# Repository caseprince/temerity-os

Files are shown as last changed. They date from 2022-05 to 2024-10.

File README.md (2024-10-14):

# temerity-os

Arduino code &amp; docs for bike-mounted rainbow LEDs

Bicycle with Rainbow LEDs

## CAD Models for 3D Printing Designed in OnShape

- [Control Unit Enclosure & Brackets](https://cad.onshape.com/documents/c0d84c6ffa9bdc5b4e96d84a/w/ab7fa442840c19dcdb86b606/e/6a70e81d8de3d289a5feaf4a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)
- [LED brackets](https://cad.onshape.com/documents/a2c029861f4f6949a2b490da/w/bb1c7454e5ed916324910a7b/e/fb98fe964bbb7c3be6a0288d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) for [silicone diffused NeoPixel strips](https://www.adafruit.com/product/3869)

## Toolpaths for laser-cut acrylic back & face plates

- https://github.com/caseprince/temerity-os/tree/main/lazer-toolpaths
- https://www.ponoko.com/ is a great option

## Full Hardware List & Notes

1. 12v Battery. [This one from TalentCell](https://talentcell.com/lithium-ion-battery/12v/pb120b1.html) works well and lasts all night. A LiFePO4 like [this one from Bioenno](https://powerwerx.com/bioenno-blf-1212a-12v-12ah-lithium-iron-pvc) might also be a sweet spot (needs testing.)
2. [Female 12v DC Power Jack Connector](https://www.amazon.com/Ksmile%C2%AE-Female-2-1x5-5mm-Adapter-Connector/dp/B015OCV5Y8/) & cable.
3. Main board is a [Feather](https://learn.adafruit.com/adafruit-feather/overview) from Adafruit: [HalloWing M4](https://www.adafruit.com/product/4300) ([DigiKey links](https://www.digikey.com/en/products/category/evaluation-boards/2041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) may be available for stuff that's out of stock on adafruit.com. There are many [Feathers](https://learn.adafruit.com/adafruit-feather/overview) to choose from, but the HalloWing is shaped like a 💀!)
4. 3.3V Converter for powering Feather: [MPM3610 3.3V Buck Converter Breakout - 21V In 3.3V Out at 1.2A](https://www.adafruit.com/product/4683)
5. [NEOPXL8 FeatherWing](https://www.adafruit.com/product/3249) - This allows for 7-8 NeoPixel channels ([8 if I could figure out compatible pin assignment?](https://forums.adafruit.com/viewtopic.php?p=964067#p964067)), and the screw-down-connection headers allow for easy wiring directly to JST connectors (below).
6. [NeoPixel RGB Neon-like LED Flex Strip with Silicone Tube - 1 meter](https://www.adafruit.com/product/3869) - These are powered directly from the 12V battery.
7. [NeoTrellis](https://learn.adafruit.com/adafruit-neotrellis) with [Silicone Elastomer 4x4 Button Keypad](https://www.adafruit.com/product/1611)- I2C neopixel buttons!
8. Bits and Bobs: [JST Connectors x10](https://www.adafruit.com/product/1663), [White Nylon Machine Screw and Stand-off Set – M2.5 Thread](https://www.adafruit.com/product/3658), [Heat Shrink Pack](https://www.adafruit.com/product/344), 500–1000+ µF Capacitor as per [Adafruit NeoPixel Überguide](https://learn.adafruit.com/adafruit-neopixel-uberguide/best-practices)
9. USB routing for external programming port: [Micro USB elbow thing](https://www.aliexpress.us/item/3256803950842339.html), [Panel Mount Extension](https://www.adafruit.com/product/3258)

### Optional Upgrade

1. [DotStar Digital LED Strips](https://www.adafruit.com/product/2328) - These require beefy 5v converters, eg: [UBEC DC/DC Step-Down (Buck) Converter - 5V @ 3A output](https://www.adafruit.com/product/1385)

### Future Features

- There are 2 holes in the enclosure sized for [Panel Mount 1/8" / 3.5mm TRS Audio Jack Connectors](https://www.adafruit.com/product/3692). These could be for external GPIO, audio in and/or out for sound reactivity, BPM detection, or bicycle bell sound-effects?

### Some Modes:

## Spinning Beachball of Death

Bicycle with Animated Rainbow LEDs

*All the pixels know where they are relative to each other in 3D space with XYZ coords, which makes it a joy to program spatial animations like this rotating rainbow.*

## Green Bounce
Bicycle with Animated Bouncing LEDs

## Purple Sine
Bicycle with Animated Purple LEDs

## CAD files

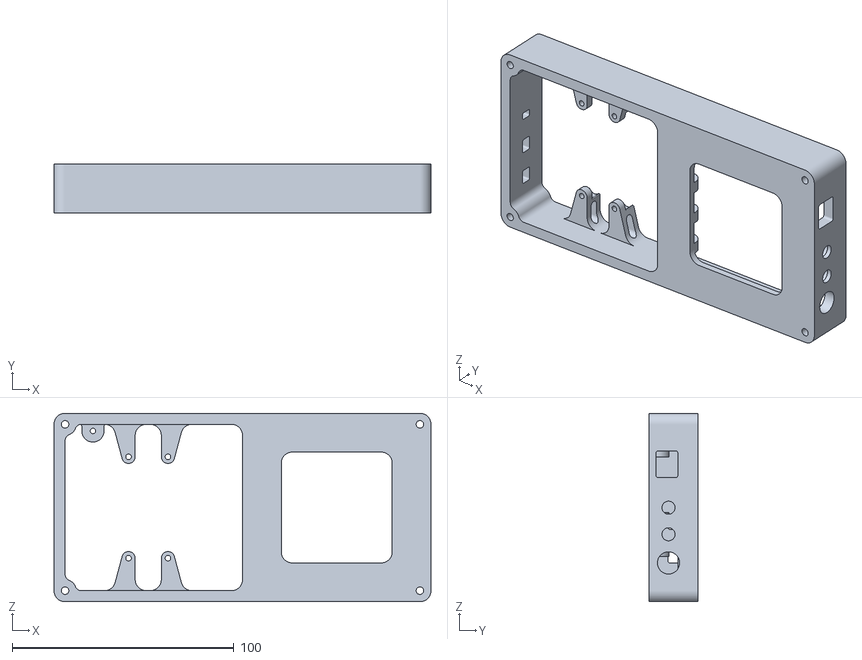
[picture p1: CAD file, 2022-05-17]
yemerityHelm_primaryModuleBody.stl
170.0 x 22.0 x 85.0

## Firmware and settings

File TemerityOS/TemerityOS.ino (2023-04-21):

const unsigned char eyes []PROGMEM = {
  0x0, 0x0, 0x0, 0x0, 0x0, 0x0, 0x0, 0x0, 0x0, 0x0, 0x0, 0x0, 0x0, 0x0, 0x0, 0x0, 0x0, 0x0, 0x0, 0x0, 0x0, 0x0, 0x0, 0x0, 0x0, 0x0, 0x0, 0x0, 0x0, 0x0,
  0x0, 0x0, 0x0, 0x0, 0x0, 0x0, 0x0, 0x0, 0x0, 0x0, 0x0, 0x0, 0x0, 0x0, 0x0, 0x0, 0x0, 0x0, 0x0, 0x0, 0x0, 0x0, 0x0, 0x0, 0x0, 0x0, 0x0, 0x0, 0x0, 0x0,
  0x0, 0x7f, 0xe0, 0x0, 0x0, 0x0, 0x0, 0x0, 0x0, 0x0, 0x0, 0x0, 0x0, 0x0, 0x0, 0x0, 0x0, 0x0, 0x0, 0x0, 0x0, 0x0, 0x0, 0x0, 0x0, 0x0, 0x0, 0x0, 0xff, 0xc0,
  0x1, 0xff, 0xff, 0xc0, 0x0, 0x0, 0x0, 0x0, 0x0, 0x0, 0x0, 0x0, 0x0, 0x0, 0x0, 0x0, 0x0, 0x0, 0x0, 0x0, 0x0, 0x0, 0x0, 0x0, 0x0, 0x0, 0x0, 0x7f, 0xff, 0xf0,
  0x3, 0xff, 0xff, 0xff, 0xc0, 0x0, 0x0, 0x0, 0x0, 0x0, 0x0, 0x0, 0x0, 0x0, 0x0, 0x0, 0x0, 0x0, 0x0, 0x0, 0x0, 0x0, 0x0, 0x0, 0x0, 0x0, 0x7f, 0xff, 0xff, 0xfc,
  0x7, 0xff, 0xff, 0xff, 0xff, 0xc0, 0x0, 0x0, 0x0, 0x0, 0x0, 0x0, 0x0, 0x0, 0x0, 0x0, 0x0, 0x0, 0x0, 0x0, 0x0, 0x0, 0x0, 0x0, 0x0, 0x7f, 0xff, 0xff, 0xff, 0xfc,
  0xf, 0xff, 0xff, 0xff, 0xff, 0xff, 0x80, 0x0, 0x0, 0x0, 0x0, 0x0, 0x0, 0x0, 0x0, 0x0, 0x0, 0x0, 0x0, 0x0, 0x0, 0x0, 0x0, 0x0, 0x3f, 0xff, 0xff, 0xff, 0xff, 0xfe,
  0xf, 0xff, 0xff, 0xff, 0xff, 0xff, 0xff, 0x0, 0x0, 0x0, 0x0, 0x0, 0x0, 0x0, 0x0, 0x0, 0x0, 0x0, 0x0, 0x0, 0x0, 0x0, 0x0, 0x1f, 0xff, 0xff, 0xff, 0xff, 0xff, 0xff,
  0xf, 0xff, 0xff, 0xff, 0xff, 0xff, 0xff, 0xfc, 0x0, 0x0, 0x0, 0x0, 0x0, 0x0, 0x0, 0x0, 0x0, 0x0, 0x0, 0x0, 0x0, 0x0, 0x7, 0xff, 0xff, 0xff, 0xff, 0xff, 0xff, 0xff,
  0x1f, 0xff, 0xff, 0xff, 0xff, 0xff, 0xff, 0xff, 0xf0, 0x0, 0x0, 0x0, 0x0, 0x0, 0x0, 0x0, 0x0, 0x0, 0x0, 0x0, 0x0, 0x0, 0xff, 0xff, 0xff, 0xff, 0xff, 0xff, 0xff, 0xff,
  0x1f, 0xff, 0xff, 0xff, 0xff, 0xff, 0xff, 0xff, 0xff, 0x0, 0x0, 0x0, 0x0, 0x0, 0x0, 0x0, 0x0, 0x0, 0x0, 0x0, 0x0, 0x1f, 0xff, 0xff, 0xff, 0xff, 0xff, 0xff, 0xff, 0xff,
  0x1f, 0xff, 0xff, 0xff, 0xff, 0xff, 0xff, 0xff, 0xff, 0xf8, 0x0, 0x0, 0x0, 0x0, 0x0, 0x0, 0x0, 0x0, 0x0, 0x0, 0x1, 0xff, 0xff, 0xff, 0xff, 0xff, 0xff, 0xff, 0xff, 0xff,
  0x1f, 0xff, 0xff, 0xff, 0xff, 0xff, 0xff, 0xff, 0xff, 0xff, 0x0, 0x0, 0x0, 0x0, 0x0, 0x0, 0x0, 0x0, 0x0, 0x0, 0x1f, 0xff, 0xff, 0xff, 0xff, 0xff, 0xff, 0xff, 0xff, 0xff,
  0x1f, 0xff, 0xff, 0xff, 0xff, 0xff, 0xff, 0xff, 0xff, 0xff, 0xe0, 0x0, 0x0, 0x0, 0x0, 0x0, 0x0, 0x0, 0x0, 0x0, 0xff, 0xff, 0xff, 0xff, 0xff, 0xff, 0xff, 0xff, 0xff, 0xff,
  0x1f, 0xff, 0xff, 0xff, 0xff, 0xff, 0xff, 0xff, 0xff, 0xff, 0xfc, 0x0, 0x0, 0x0, 0x0, 0x0, 0x0, 0x0, 0x0, 0x7, 0xff, 0xff, 0xff, 0xff, 0xff, 0xff, 0xff, 0xff, 0xff, 0xff,
  0x1f, 0xff, 0xff, 0xff, 0xff, 0xff, 0xff, 0xff, 0xff, 0xff, 0xff, 0x80, 0x0, 0x0, 0x0, 0x0, 0x0, 0x0, 0x0, 0x3f, 0xff, 0xff, 0xff, 0xff, 0xff, 0xff, 0xff, 0xff, 0xff, 0xff,
  0x1f, 0xff, 0xff, 0xff, 0xff, 0xff, 0xff, 0xff, 0xff, 0xff, 0xff, 0xe0, 0x0, 0x0, 0x0, 0x0, 0x0, 0x0, 0x0, 0xff, 0xff, 0xff, 0xff, 0xff, 0xff, 0xff, 0xff, 0xff, 0xff, 0xff,
  0x1f, 0xff, 0xff, 0xff, 0xff, 0xff, 0xff, 0xff, 0xff, 0xff, 0xff, 0xf8, 0x0, 0x0, 0x0, 0x0, 0x0, 0x0, 0x3, 0xff, 0xff, 0xff, 0xff, 0xff, 0xff, 0xff, 0xff, 0xff, 0xff, 0xff,
  0x1f, 0xff, 0xff, 0xff, 0xff, 0xff, 0xff, 0xff, 0xff, 0xff, 0xff, 0xfe, 0x0, 0x0, 0x0, 0x0, 0x0, 0x0, 0xf, 0xff, 0xff, 0xff, 0xff, 0xff, 0xff, 0xff, 0xff, 0xff, 0xff, 0xff,
  0xf, 0xff, 0xff, 0xff, 0xff, 0xff, 0xff, 0xff, 0xff, 0xff, 0xff, 0xff, 0x0, 0x0, 0x0, 0x0, 0x0, 0x0, 0x1f, 0xff, 0xff, 0xff, 0xff, 0xff, 0xff, 0xff, 0xff, 0xff, 0xff, 0xff,
  0xf, 0xff, 0xff, 0xff, 0xff, 0xff, 0xff, 0xff, 0xff, 0xff, 0xff, 0xff, 0xc0, 0x0, 0x0, 0x0, 0x0, 0x0, 0x3f, 0xff, 0xff, 0xff, 0xff, 0xff, 0xff, 0xff, 0xff, 0xff, 0xff, 0xff,
  0xf, 0xff, 0xff, 0xff, 0xff, 0xff, 0xff, 0xff, 0xff, 0xff, 0xff, 0xff, 0xe0, 0x0, 0x0, 0x0, 0x0, 0x0, 0xff, 0xff, 0xff, 0xff, 0xff, 0xff, 0xff, 0xff, 0xff, 0xff, 0xff, 0xff,
  0xf, 0xff, 0xff, 0xff, 0xff, 0xff, 0xff, 0xff, 0xff, 0xff, 0xff, 0xff, 0xf0, 0x0, 0x0, 0x0, 0x0, 0x1, 0xff, 0xff, 0xff, 0xff, 0xff, 0xff, 0xff, 0xff, 0xff, 0xff, 0xff, 0xff,
  0xf, 0xff, 0xff, 0xff, 0xff, 0xff, 0xff, 0xff, 0xff, 0xff, 0xff, 0xff, 0xf8, 0x0, 0x0, 0x0, 0x0, 0x3, 0xff, 0xff, 0xff, 0xff, 0xff, 0xff, 0xff, 0xff, 0xff, 0xff, 0xff, 0xff,
  0xf, 0xff, 0xff, 0xff, 0xff, 0xff, 0xff, 0xff, 0xff, 0xff, 0xff, 0xff, 0xfc, 0x0, 0x0, 0x0, 0x0, 0x7, 0xff, 0xff, 0xff, 0xff, 0xff, 0xff, 0xff, 0xff, 0xff, 0xff, 0xff, 0xff,
  0x7, 0xff, 0xff, 0xff, 0xff, 0xff, 0xff, 0xff, 0xff, 0xff, 0xff, 0xff, 0xfe, 0x0, 0x0, 0x0, 0x0, 0x7, 0xff, 0xff, 0xff, 0xff, 0xff, 0xff, 0xff, 0xff, 0xff, 0xff, 0xff, 0xff,
  0x7, 0xff, 0xff, 0xff, 0xff, 0xff, 0xff, 0xff, 0xff, 0xff, 0xff, 0xff, 0xfe, 0x0, 0x0, 0x0, 0x0, 0xf, 0xff, 0xff, 0xff, 0xff, 0xff, 0xff, 0xff, 0xff, 0xff, 0xff, 0xff, 0xff,
  0x7, 0xff, 0xff, 0xff, 0xff, 0xff, 0xff, 0xff, 0xff, 0xff, 0xff, 0xff, 0xff, 0x0, 0x0, 0x0, 0x0, 0x1f, 0xff, 0xff, 0xff, 0xff, 0xff, 0xff, 0xff, 0xff, 0xff, 0xff, 0xff, 0xfe,
  0x7, 0xff, 0xff, 0xff, 0xff, 0xff, 0xff, 0xff, 0xff, 0xff, 0xff, 0xff, 0xff, 0x80, 0x0, 0x0, 0x0, 0x1f, 0xff, 0xff, 0xff, 0xff, 0xff, 0xff, 0xff, 0xff, 0xff, 0xff, 0xff, 0xfe,
  0x7, 0xff, 0xff, 0xff, 0xff, 0xff, 0xff, 0xff, 0xff, 0xff, 0xff, 0xff, 0xff, 0x80, 0x0, 0x0, 0x0, 0x3f, 0xff, 0xff, 0xff, 0xff, 0xff, 0xff, 0xff, 0xff, 0xff, 0xff, 0xff, 0xfe,
  0x3, 0xff, 0xff, 0xff, 0xff, 0xff, 0xff, 0xff, 0xff, 0xff, 0xff, 0xff, 0xff, 0xc0, 0x0, 0x0, 0x0, 0x7f, 0xff, 0xff, 0xff, 0xff, 0xff, 0xff, 0xff, 0xff, 0xff, 0xff, 0xff, 0xfe,
  0x3, 0xff, 0xff, 0xff, 0xff, 0xff, 0xff, 0xff, 0xff, 0xff, 0xff, 0xff, 0xff, 0xc0, 0x0, 0x0, 0x0, 0x7f, 0xff, 0xff, 0xff, 0xff, 0xff, 0xff, 0xff, 0xff, 0xff, 0xff, 0xff, 0xfc,
  0x3, 0xff, 0xff, 0xff, 0xff, 0xff, 0xff, 0xff, 0xff, 0xff, 0xff, 0xff, 0xff, 0xe0, 0x0, 0x0, 0x0, 0x7f, 0xff, 0xff, 0xff, 0xff, 0xff, 0xff, 0xff, 0xff, 0xff, 0xff, 0xff, 0xfc,
  0x3, 0xff, 0xff, 0xff, 0xff, 0xff, 0xff, 0xff, 0xff, 0xff, 0xff, 0xff, 0xff, 0xe0, 0x0, 0x0, 0x0, 0xff, 0xff, 0xff, 0xff, 0xff, 0xff, 0xff, 0xff, 0xff, 0xff, 0xff, 0xff, 0xfc,
  0x3, 0xff, 0xff, 0xff, 0xff, 0xff, 0xff, 0xff, 0xff, 0xff, 0xff, 0xff, 0xff, 0xe0, 0x0, 0x0, 0x0, 0xff, 0xff, 0xff, 0xff, 0xff, 0xff, 0xff, 0xff, 0xff, 0xff, 0xff, 0xff, 0xfc,
  0x1, 0xff, 0xff, 0xff, 0xff, 0xff, 0xff, 0xff, 0xff, 0xff, 0xff, 0xff, 0xff, 0xf0, 0x0, 0x0, 0x0, 0xff, 0xff, 0xff, 0xff, 0xff, 0xff, 0xff, 0xff, 0xff, 0xff, 0xff, 0xff, 0xf8,
  0x1, 0xff, 0xff, 0xff, 0xff, 0xff, 0xff, 0xff, 0xff, 0xff, 0xff, 0xff, 0xff, 0xf0, 0x0, 0x0, 0x0, 0xff, 0xff, 0xff, 0xff, 0xff, 0xff, 0xff, 0xff, 0xff, 0xff, 0xff, 0xff, 0xf8,
  0x1, 0xff, 0xff, 0xff, 0xff, 0xff, 0xff, 0xff, 0xff, 0xff, 0xff, 0xff, 0xff, 0xf0, 0x0, 0x0, 0x0, 0xff, 0xff, 0xff, 0xff, 0xff, 0xff, 0xff, 0xff, 0xff, 0xff, 0xff, 0xff, 0xf8,
  0x1, 0xff, 0xff, 0xff, 0xff, 0xff, 0xff, 0xff, 0xff, 0xff, 0xff, 0xff, 0xff, 0xf0, 0x0, 0x0, 0x0, 0xff, 0xff, 0xff, 0xff, 0xff, 0xff, 0xff, 0xff, 0xff, 0xff, 0xff, 0xff, 0xf8,
  0x1, 0xff, 0xff, 0xff, 0xff, 0xff, 0xff, 0xff, 0xff, 0xff, 0xff, 0xff, 0xff, 0xf0, 0x0, 0x0, 0x0, 0xff, 0xff, 0xff, 0xff, 0xff, 0xff, 0xff, 0xff, 0xff, 0xff, 0xff, 0xff, 0xf0,
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
};

enum turnSignalStates {
  OFF, 
  LEFT,
  STARBOARD
};
turnSignalStates turnSignalState = OFF;

enum shieldModes {
  ROTATING_RAINBOW,
  HORIZ_RAINBOW,
  CONIC_RAINBOW,
  ORANGE_SIN,
  SPARKLE_PARTY,
  PURPLE_PINK,
  BLUE_GREEN,
  CYLON,
  AUDIT,
  COORD_TEST,
  BORING_MODE,
  HAZARD,
  AMERICA_FUCK_YEAH,
  NONE
};
shieldModes shieldMode = CONIC_RAINBOW;
shieldModes shieldModeJustWas = NONE;
bool showDotstars = true;


#define MAX16BIT 65535

// DOTSTARs
#include <Adafruit_DotStar.h>
#include <SPI.h>
#define NUMDOTSTARS 288 // Number of dotstars
#define DATAPIN    3
#define CLOCKPIN   2
Adafruit_DotStar dotstars(NUMDOTSTARS, DATAPIN, CLOCKPIN, DOTSTAR_BGR);
// Hardware SPI is a little faster, but must be wired to specific pins
// (Arduino Uno = pin 11 for data, 13 for clock, other boards are different).
//Adafruit_DotStar dotstars(NUMDOTSTARS, DOTSTAR_BRG);
uint32_t dotstarHueOffset = 0;

// Onboard Screen
#include <Adafruit_GFX.h>    // Core graphics library
#include <Adafruit_ST7789.h> // Hardware-specific library for ST7789
#include <SPI.h>
#define TFT_CS        44 // PyBadge/PyGamer display control pins: chip select
#define TFT_RST       46 // Display reset
#define TFT_DC        45 // Display data/command select
#define TFT_BACKLIGHT 47 // Display backlight pin
Adafruit_ST7789 tft = Adafruit_ST7789(&SPI1, TFT_CS, TFT_DC, TFT_RST);
// Custom colors
#define ST77XX_ORANGE_YEL 0xFDC0
#define ST77XX_ORANGE_RED 0xFB80
#define ST77XX_ORANGE_DK 0xA240

// NeoPXL8 8 x 20
#include <Adafruit_NeoPXL8.h>
#define NUM_LED 20  // Per strand. Total number of pixels is 8X this!
#define NUM_NEON 160
// Here's a pinout that works with the Feather M4 (w/NeoPXL8 M4 FeatherWing):
int8_t pins[8] = { SCK, 5, 9, 6, 13, 12, 11, 10 };
// Alternates are available for the last 4 pins:
// int8_t pins[8] = { 13, 12, 11, 10, PIN_SERIAL1_RX, PIN_SERIAL1_TX, SCL, SDA };
Adafruit_NeoPXL8 neonLEDs(NUM_LED, pins, NEO_GRB);

// Onboard LEDs
Adafruit_NeoPixel onboardLEDs(4, 8, NEO_GRB + NEO_KHZ800);

// NeoTrellis
#include "Adafruit_NeoTrellis.h"
Adafruit_NeoTrellis trellis;
boolean isDown[16];
uint8_t brightness = 127;
TrellisCallback blink(keyEvent evt) {
  // Check is the pad pressed?
  if (evt.bit.EDGE == SEESAW_KEYPAD_EDGE_RISING) {
    trellis.pixels.setPixelColor(evt.bit.NUM, Wheel(map(evt.bit.NUM, 0, trellis.pixels.numPixels(), 0, 255))); // on rising
    
    if (evt.bit.NUM == 3) {
      if (brightness < 255) {
        brightness += 32;
        neonLEDs.setBrightness(brightness);
        drawConsole("Brightness " + String(brightness));
      }
    } else if (evt.bit.NUM == 7) {
      if (brightness > 16) {
        brightness -= 32;
        neonLEDs.setBrightness(brightness);
        drawConsole("Brightness " + String(brightness));
      }
    } else if (evt.bit.NUM == 12 || evt.bit.NUM == 13 || evt.bit.NUM == 15) {
      // Do nothing here for momentary buttons
    } else {
      drawConsole("Press " + String(evt.bit.NUM));
      if (evt.bit.NUM == 0) {
        if (shieldMode == ROTATING_RAINBOW) {
          shieldMode = HORIZ_RAINBOW;
        } else if (shieldMode == HORIZ_RAINBOW) {
          shieldMode = CONIC_RAINBOW;
        } else if (shieldMode == CONIC_RAINBOW) {
          shieldMode = ROTATING_RAINBOW;
        }        
      } else if (evt.bit.NUM == 1) {
        shieldMode = ORANGE_SIN;
      } else if (evt.bit.NUM == 2) {
        shieldMode = SPARKLE_PARTY;
      } else if (evt.bit.NUM == 4) {
        shieldMode = PURPLE_PINK;
      } else if (evt.bit.NUM == 5) {
        shieldMode = BLUE_GREEN;
      } else if (evt.bit.NUM == 6) {
        shieldMode = CYLON;
      } else if (evt.bit.NUM == 8) {
        shieldMode = AMERICA_FUCK_YEAH;
      } else if (evt.bit.NUM == 9) {
        shieldMode = COORD_TEST;
      } else if (evt.bit.NUM == 10) {
        shieldMode = HAZARD;      
      } else if (evt.bit.NUM == 11) {
        shieldMode = BORING_MODE;
      } else if (evt.bit.NUM == 14) {
        showDotstars = !showDotstars;
      } else {
        shieldMode = NONE;
      }
    }

    if (evt.bit.NUM == 12) {
      if (turnSignalState != LEFT) {
        turnSignalState = LEFT;
      } else {
        turnSignalState = OFF;
      }
    } else if (evt.bit.NUM == 13) {
      if (turnSignalState != STARBOARD) {
        turnSignalState = STARBOARD;
      } else {
        turnSignalState = OFF;
      }
    } else {
      turnSignalState = OFF;
    }
    isDown[evt.bit.NUM] = true;
  } else if (evt.bit.EDGE == SEESAW_KEYPAD_EDGE_FALLING) {
    // or is the pad released?
    isDown[evt.bit.NUM] = false;
    trellis.pixels.setPixelColor(evt.bit.NUM, 0); //off falling
  }

  // Turn on/off the neopixels!
  trellis.pixels.show();

  return 0;
}

/************* COORDS **************/
// All measurements are in mm
const float DEG2RAD = PI / 180.0f;
const float RAD2DEG = 180.0f / PI;
const float FORK_ANGLE = -120.0 * DEG2RAD;
const float FORK_Z_OFFSET = 72;
const float TOP_ANGLE = -8.0 * DEG2RAD;
const float BOTTOM_ANGLE = -30.0 * DEG2RAD;
const float HELM_ANGLEZ = 60 * DEG2RAD;
const float HELM_ANGLEX = 75 * DEG2RAD;

const float NEON_DIST = 49.0;
float neonLEDs_x[8 * NUM_LED];
float neonLEDs_y[8 * NUM_LED];
float neonLEDs_z[8 * NUM_LED];
float LEDs_xMin = 0.0;
float LEDs_yMin = 0.0;
float LEDs_zMin = 0.0;
float LEDs_xMax = 0.0;
float LEDs_yMax = 0.0;
float LEDs_zMax = 0.0;

const float DOTSTAR_DIST = 6.95;
float dotstarLEDs_x[NUMDOTSTARS];
float dotstarLEDs_y[NUMDOTSTARS];
float dotstarLEDs_z[NUMDOTSTARS];

float coordTest_x = 0.0;
float coordTest_y = 0.0;
float coordTest_z = 0.0;

uint8_t sparkles_r[8 * NUM_LED];
uint8_t sparkles_g[8 * NUM_LED];
uint8_t sparkles_b[8 * NUM_LED];

/************* SETUP **************/
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
void loop() {
  ms_elapsed = millis() - millis_last;
  msSinceNeoPixelPush += ms_elapsed;
  tft.setCursor(160, 0);
  tft.setTextSize(1);
  tft.setTextColor(ST77XX_ORANGE, ST77XX_BLACK);
  tft.print("MS: ");
  tft.print(ms_elapsed);
  tft.print("       ");

  trellis.read();  // interrupt management does all the work! :)
  bool animateNeon = true;
  if (shieldMode == CONIC_RAINBOW) {
    for (uint8_t i = 0; i < NUM_NEON; i++) {
      float hueAngle = atan2(neonLEDs_y[i] - 550.0, neonLEDs_x[i] - LEDs_xMax / 2.0 + 100.0);
      uint16_t hue = ((hueAngle + PI) / TWO_PI) * MAX16BIT;
      hue -= millis() * 30;
      neonLEDs.setPixelColor(i, neonLEDs.ColorHSV(hue, 255, 255));
    }
    for (uint16_t i = 0; i < NUMDOTSTARS; i++) {
      float hueAngle = atan2(dotstarLEDs_y[i] - 550.0, dotstarLEDs_x[i] - LEDs_xMax / 2.0 + 100.0);
      uint16_t hue = ((hueAngle + PI) / TWO_PI) * MAX16BIT;
      hue -= millis() * 30;
      dotstars.setPixelColor(i, dotstars.ColorHSV(hue, 255, 55));
    }
  } else if (shieldMode == HORIZ_RAINBOW) {
    for (uint8_t i = 0; i < NUM_NEON; i++) {
      uint16_t hue = (neonLEDs_x[i] * -50) + (millis() * 10);
      neonLEDs.setPixelColor(i, neonLEDs.ColorHSV(hue, 255, 255));
    }
    for (uint16_t i = 0; i < NUMDOTSTARS; i++) {
      uint16_t hue = (dotstarLEDs_y[i] * -150) + (millis() * 50);
      dotstars.setPixelColor(i, dotstars.ColorHSV(hue, 255, 55));
    }
  } else if (shieldMode == ROTATING_RAINBOW) {  
    float hueRotX = cos(millis() * 0.001);
    float hueRotY = sin(millis() * 0.001);
    float pt1[2] = {0, 0};
    float pt2[2] = {hueRotX, hueRotY};
    float pt3[2];

    // ROTATING RAINBOW!:
    for (uint8_t i = 0; i < NUM_NEON; i++) {
      pt3[0] = neonLEDs_x[i] - LEDs_xMax/2; // Offset LED pt to center rainbow rotation
      pt3[1] = neonLEDs_y[i] - LEDs_yMax/2;
      float hueDist = LineToPointDistance2D(pt1, pt2, pt3, false);
      uint16_t hue = (hueDist * -50) + (millis() * 10);
      neonLEDs.setPixelColor(i, neonLEDs.ColorHSV(hue, 255, 255));
    }

    // knot?
    for (uint16_t i = 0; i < NUMDOTSTARS; i++) {
      pt3[0] = dotstarLEDs_x[i] - LEDs_xMax/2; // Offset LED pt to center rainbow rotation
      pt3[1] = dotstarLEDs_y[i] - LEDs_yMax/2;
      float hueDist = LineToPointDistance2D(pt1, pt2, pt3, false);
      uint16_t hue = (hueDist * -50) + (millis() * 10);
      uint32_t rgbcolor = dotstars.ColorHSV(hue, 255, 16);
      dotstars.setPixelColor(i, rgbcolor);
      dotstarHueOffset += 10;

      uint32_t rgbcolorDisplay = dotstars.ColorHSV(hue, 255, 255);
      tft.drawPixel(0, i + 30, tft.color565(getRedValueFromColor(rgbcolorDisplay), getGreenValueFromColor(rgbcolorDisplay), getBlueValueFromColor(rgbcolorDisplay)));
    }

    onboardLEDs.setPixelColor(0, Wheel(((millis() / 200) + 0) * 3.5));
    onboardLEDs.setPixelColor(1, Wheel(((millis() / 200) + 10) * 3.5));
    onboardLEDs.setPixelColor(2, Wheel(((millis() / 200) + 20) * 3.5));
    onboardLEDs.setPixelColor(3, Wheel(((millis() / 200) + 30) * 3.5));
    trellis.pixels.setBrightness(50);
    for (uint16_t i = 0; i < trellis.pixels.numPixels(); i++) {
      trellis.pixels.setPixelColor(i, Wheel(((millis() / 200.0) + i) * 3.5));
    }
  } else if (shieldMode == ORANGE_SIN) {
    for (uint8_t i = 0; i < NUM_NEON; i++) {
      uint32_t hue = 180 + (sin((millis() / 80.0) + (i)) * 2500);
      // float macroHueSin = sin(neonLEDs_x[i] / 1000.0 - millis() / 400.0);
      // hue += macroHueSin * 3000;
      hue += (neonLEDs_y[i] / LEDs_yMax) * 8000;
      neonLEDs.setPixelColor(i, neonLEDs.ColorHSV(hue, 255, 255));
    }
    for (uint16_t i = 0; i < NUMDOTSTARS; i++) {
      uint32_t hue = 100 + (sin((millis() / 80.0) + (dotstarLEDs_x[i] / 10.0)) * 2400);
      hue += (dotstarLEDs_y[i] / LEDs_yMax) * 8000;
      dotstars.setPixelColor(i, dotstars.ColorHSV(hue, 255, 16));
      sine_offset += ms_elapsed;
    }
    onboardLEDs.setPixelColor(0, neonLEDs.Color(255, 50 + (sin((sine_offset / sine_ms) + 10) * 100), 0));
    onboardLEDs.setPixelColor(1, neonLEDs.Color(255, 50 + (sin((sine_offset / sine_ms) + 11) * 100), 0));
    onboardLEDs.setPixelColor(2, neonLEDs.Color(255, 50 + (sin((sine_offset / sine_ms) + 12) * 100), 0));
    onboardLEDs.setPixelColor(3, neonLEDs.Color(255, 50 + (sin((sine_offset / sine_ms) + 13) * 100), 0));
    for (uint16_t i = 0; i < trellis.pixels.numPixels(); i++) {
      trellis.pixels.setPixelColor(i, 0, 0, 0);
    }
    sine_offset += ms_elapsed;
    if (sine_offset > TWO_PI * sine_ms) {
      sine_offset -= TWO_PI * sine_ms;
    }
  } else if (shieldMode == SPARKLE_PARTY) {
    for (uint8_t i = 0; i < NUM_NEON; i++) {
      if (random(1000) < ms_elapsed) {
        sparkles_r[i] = uint8_t(random(255));
        sparkles_g[i] = uint8_t(random(255));
        sparkles_b[i] = uint8_t(random(255));
      }
      neonLEDs.setPixelColor(i, neonLEDs.Color(sparkles_r[i], sparkles_g[i], sparkles_b[i]));
    }
    dotstarSparkleParty();
    onboardLEDs.setPixelColor(0, neonLEDs.Color(sparkles_r[0], sparkles_g[0], sparkles_b[0]));
    onboardLEDs.setPixelColor(1, neonLEDs.Color(sparkles_r[1], sparkles_g[1], sparkles_b[1]));
    onboardLEDs.setPixelColor(2, neonLEDs.Color(sparkles_r[2], sparkles_g[2], sparkles_b[2]));
    onboardLEDs.setPixelColor(3, neonLEDs.Color(sparkles_r[3], sparkles_g[3], sparkles_b[3]));
    for (uint16_t i = 0; i < trellis.pixels.numPixels(); i++) {
       trellis.pixels.setPixelColor(i, neonLEDs.Color(sparkles_r[i+5], sparkles_g[i+5], sparkles_b[i+5]));
    }
    float fade = ms_elapsed / 4.0;
    for (uint16_t i = 0; i < sizeof(sparkles_r); i++) {
      if (sparkles_r[i] - fade > 0) {
        sparkles_r[i] -= fade;
      } else {
        sparkles_r[i] = 0;
      }
      if (sparkles_g[i] - fade > 0) {
        sparkles_g[i] -= fade;
      } else {
        sparkles_g[i] = 0;
      }
      if (sparkles_b[i] - fade > 0) {
        sparkles_b[i] -= fade;
      } else {
        sparkles_b[i] = 0;
      }
    }
  } else if (shieldMode == PURPLE_PINK) {
    for (uint16_t i = 0; i < NUMDOTSTARS; i++) {
      float pt1[2] = {dotstarLEDs_z[i], dotstarLEDs_y[i]};
      float pt2[2] = {sin(millis() / 1200.0) * 300.0, sin(millis() / 1600.0) * -300.0 + 650.0}; // - LEDs_yMax / 2.0;
      // float pt3[2] = {sin(millis() / 2100.0) * -300.0, sin(millis() / 2800.0) * 300.0 + 650.0}; // - LEDs_yMax / 2.0;
      float dist = Distance(pt1, pt2); // + Distance(pt1, pt3);
      float sinRatio = (sin(dist/10.0) + 1.0) / 2.0;
      float brightnessRatio = easeInCirc(easeInCirc(sinRatio));
      if (dist < 13) {
        dotstars.setPixelColor(i, dotstars.ColorHSV(43000, 255, 45));
      } else {
        uint32_t hue = 33000 + (1.0 - easeInCirc(sinRatio)) * 7000; // + (dotstarLEDs_y[i] * -5.0);
        hue += dist * 100.0; // rainbowify wave peaks
        if (brightnessRatio > 0.90) { // 0.90 is very sparkly!
          dotstars.setPixelColor(i, dotstars.ColorHSV(hue, 120, 195));
        } else {
          dotstars.setPixelColor(i, dotstars.ColorHSV(hue, 240, brightnessRatio * 45.0));
        }        
      }      
    }
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

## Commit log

2023-02-24 VSC config, min/max Accelerometer display
2023-03-04 Better dotstar sparkles, glitching neon
    [TemerityOS.ino]
2023-03-08 Fix NeoPXL8 pins, add audit mode
    [TemerityOS.ino]
2023-03-24 Consolidate LED mode conditionals
2023-03-29 Correctly config dotstar color order to sync rainbows
    [TemerityOS.ino]
